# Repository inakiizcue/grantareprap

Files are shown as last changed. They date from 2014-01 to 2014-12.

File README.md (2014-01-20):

grantareprap
============

Configuration, 3D models and tutorials for the prusa mendel i3 we built at the office

Folder structure:

*firmware

Tweaked version of the customized firmware by Marlin. We had to change some values in configuration.h to invert behaviour in some axis.

*Other software

Links and zip files to the rest of the software stack (printrun, slic3r, cad packages)

*3D models

.stl files for printing

How to configure a host for the printer
=======================================

Install all programs in \OtherSoftware

Open \firmware\firmware\it3 minitronics\Marlin-Marlin_v1\Marlin\Marlin.ino in arduino IDE

Connect your computer to the minitronics board in the printer with a USB cable.

Check that LED lights in the minitronics board in the printer light.

Check that all axis of the printer are free to move, the tray is clean of printed parts.

Plug the printer to a power outlet and switch on.

Check that LED lights in printer power supply are on.

Click 'File' -> 'Upload' in Arduino IDE to transfer firmware to printer.

Now the printer is ready to work.

Open \OtherSoftware\Printrun-Win-Slic3r-12July2013\pronterface.exe

Check all printing parameters correspond to the type of plastic (ABS, PLA) used.

Load the .stl or .gcode file for the model to print.

Hit 'print' button.

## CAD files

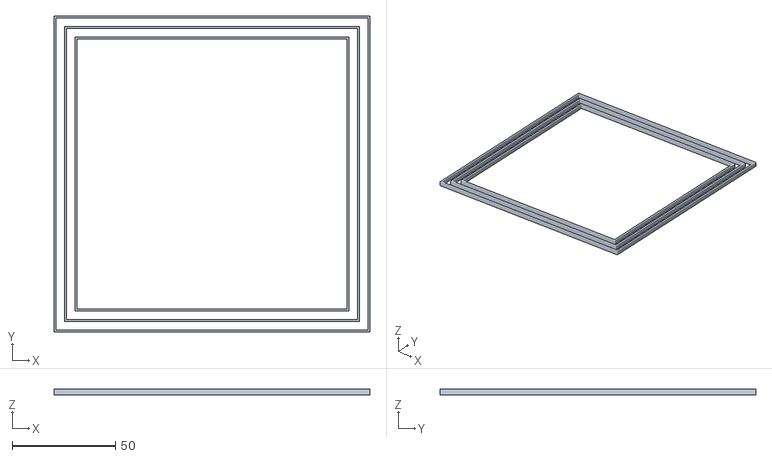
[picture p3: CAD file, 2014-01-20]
3DModels/Bed_Leveling_Calibration_test_object/bedleveling-1.stl
153.0 x 153.0 x 3.00

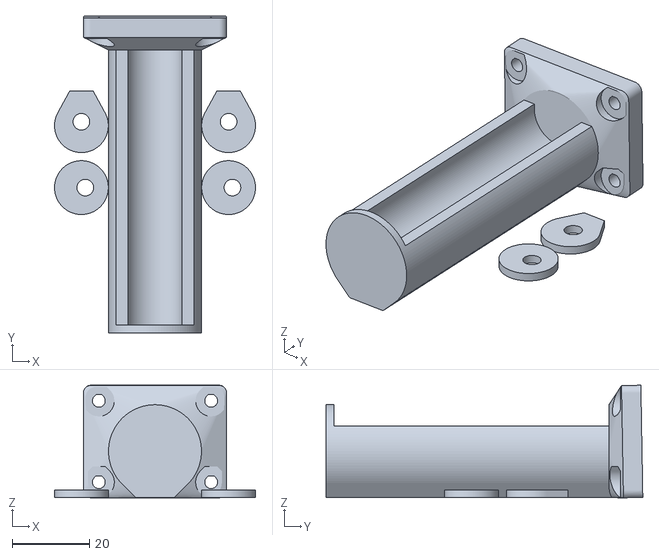
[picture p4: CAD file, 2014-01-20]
3DModels/Parametric_Mendel90_Filament_Spool_Holder/filament_holder_50.stl
51.9 x 81.8 x 29.1

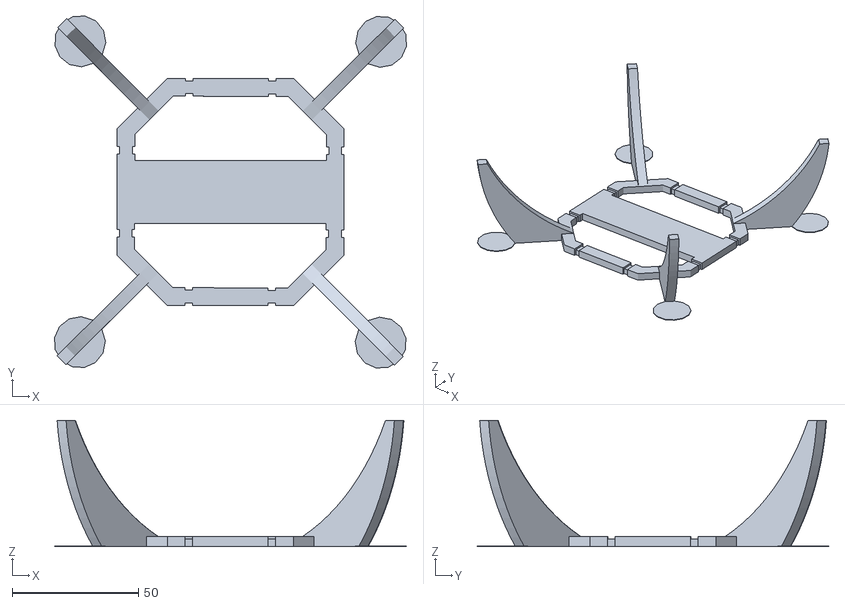
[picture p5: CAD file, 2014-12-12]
3DModels/PL2Q_Hugin/PL2Q_Hugin_legs.stl
139.4 x 139.4 x 50.1

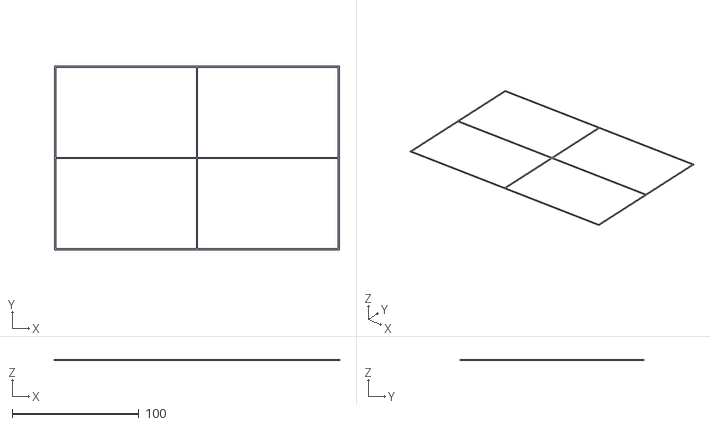
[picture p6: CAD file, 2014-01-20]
3DModels/Print_Bed_Level_Check/LevelRep-30.stl
225.0 x 145.0 x 0.3

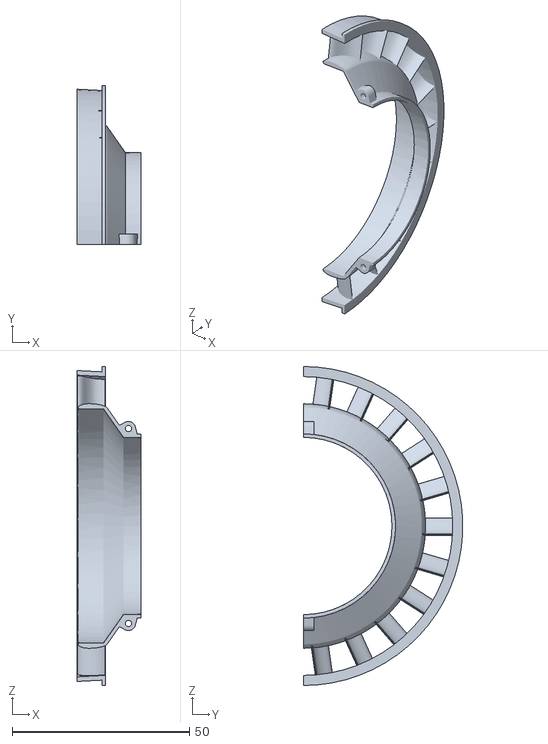
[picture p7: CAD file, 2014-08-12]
3DModels/Turbofan/Low_Bypass_Turbofan_Jet_Engine/compressor case/CC Diffuser.STL
18.0 x 44.9 x 90.0

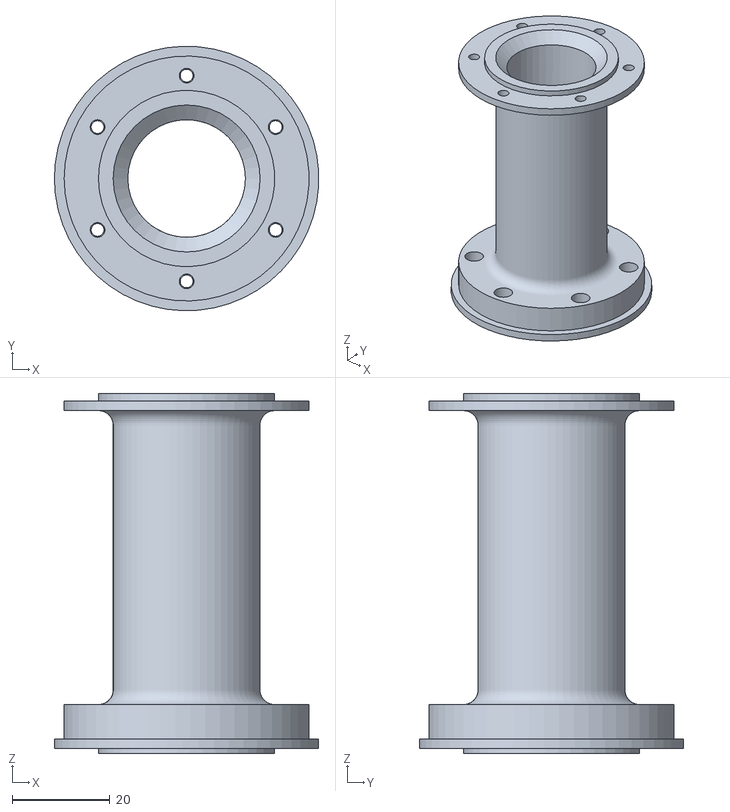
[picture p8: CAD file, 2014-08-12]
3DModels/Turbofan/Low_Bypass_Turbofan_Jet_Engine/HP rotor/spacer CC.STL
54.0 x 54.0 x 73.5

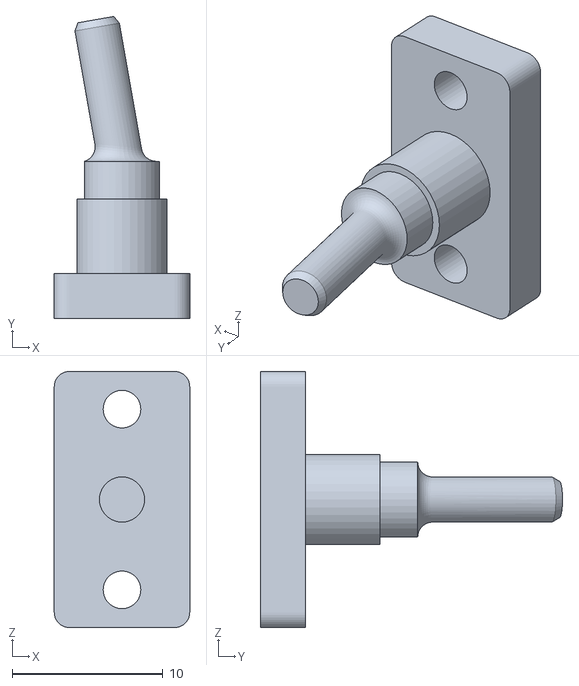
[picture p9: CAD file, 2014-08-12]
3DModels/Turbofan/Low_Bypass_Turbofan_Jet_Engine/Rev_1/fuel nozzle.STL
9.00 x 20.1 x 17.0

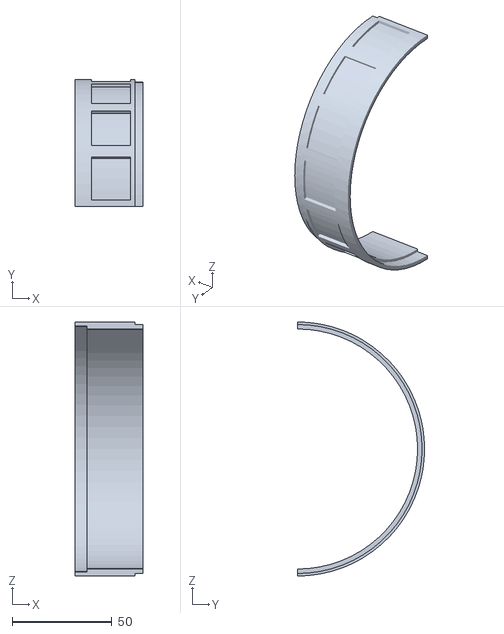
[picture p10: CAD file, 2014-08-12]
3DModels/Turbofan/Low_Bypass_Turbofan_Jet_Engine/turbine_section/turbine section/extetnal can.STL
34.0 x 63.4 x 127.0

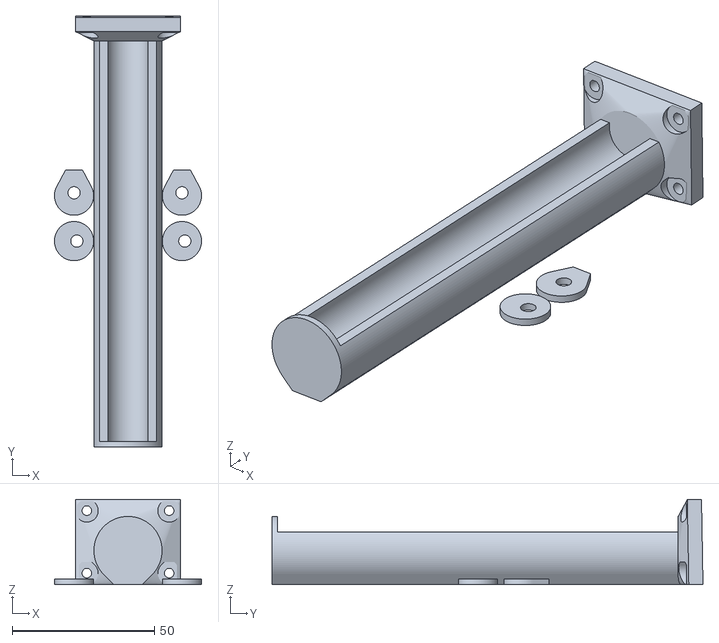
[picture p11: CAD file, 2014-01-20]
3DModels/Parametric_Mendel90_Filament_Spool_Holder/filament_holder_120.stl
51.8 x 151.8 x 30.1

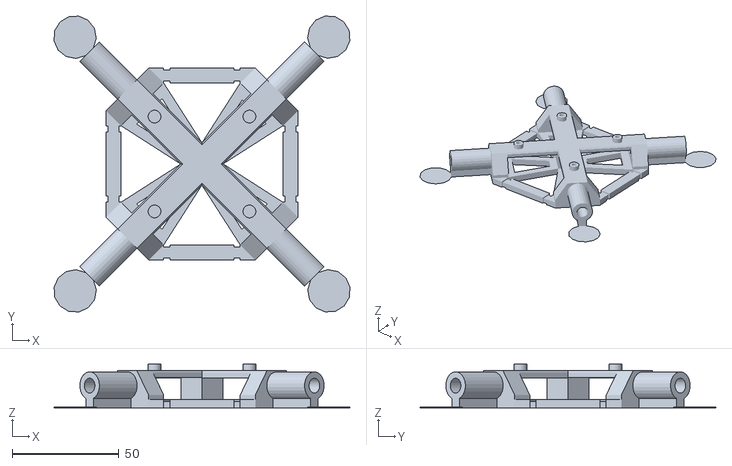
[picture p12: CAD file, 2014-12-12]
3DModels/PL2Q_Hugin/PL2Q_Hugin_body.stl
138.8 x 138.8 x 20.5

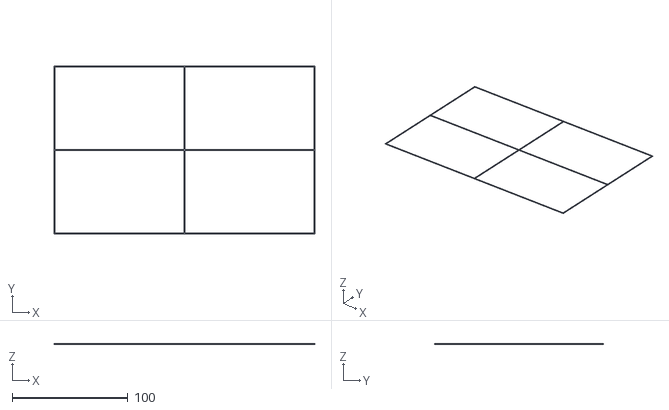
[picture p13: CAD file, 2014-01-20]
3DModels/Print_Bed_Level_Check/LevelRep-10.stl
225.0 x 145.0 x 0.1

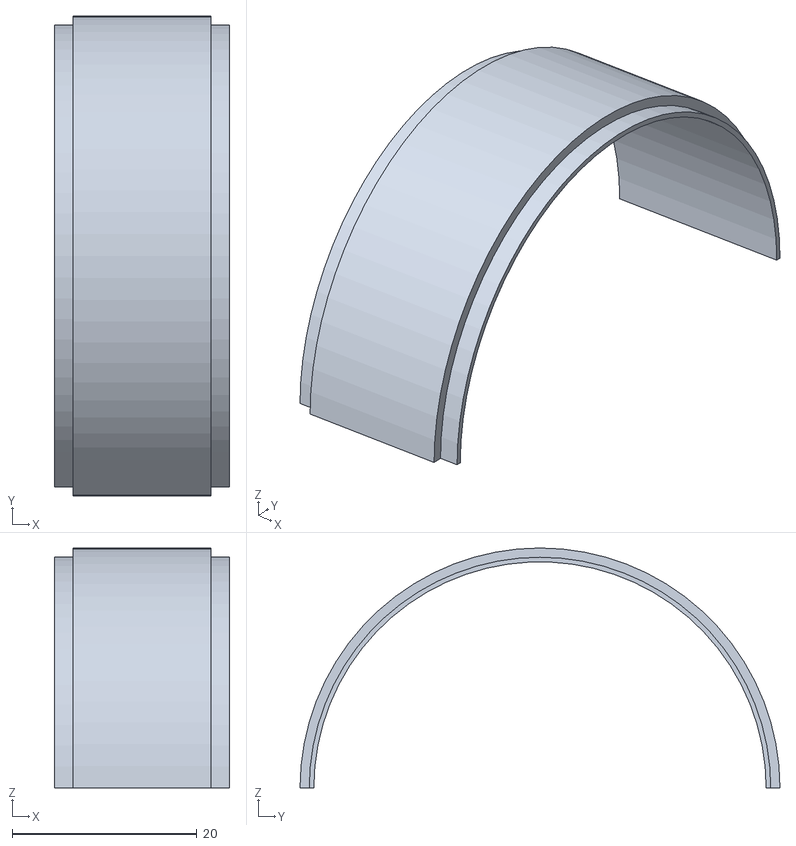
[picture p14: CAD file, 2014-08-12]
3DModels/Turbofan/Low_Bypass_Turbofan_Jet_Engine/compressor case/CC Diffuser 3.STL
19.0 x 52.0 x 26.0

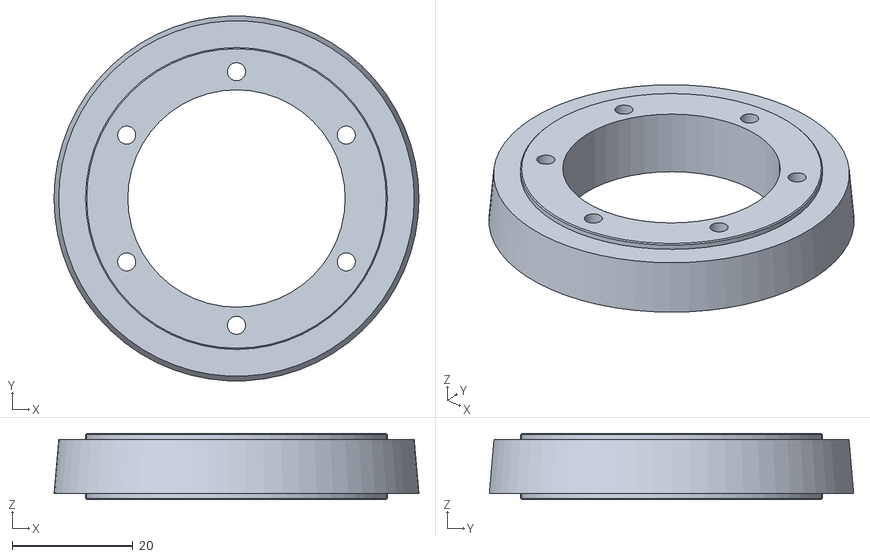
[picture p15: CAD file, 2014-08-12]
3DModels/Turbofan/Low_Bypass_Turbofan_Jet_Engine/HP rotor/R2Spacer.STL
60.5 x 60.4 x 11.0

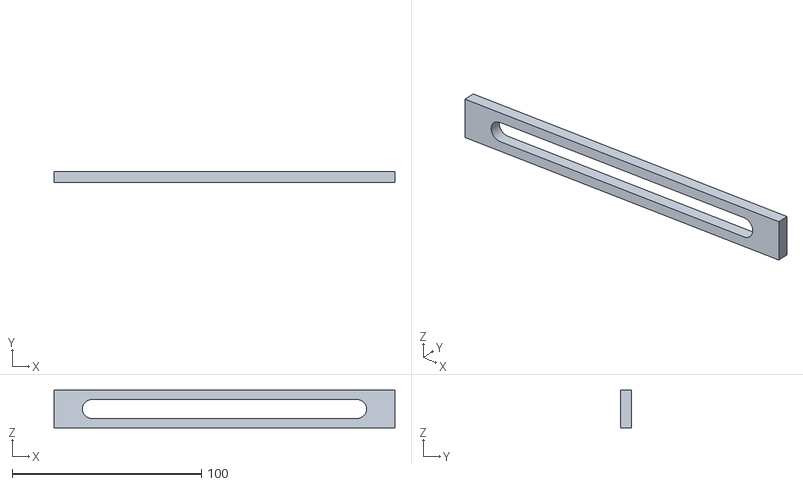
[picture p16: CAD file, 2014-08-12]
3DModels/Turbofan/Low_Bypass_Turbofan_Jet_Engine/Rev_1/distanziale.STL
180.0 x 6.00 x 20.0

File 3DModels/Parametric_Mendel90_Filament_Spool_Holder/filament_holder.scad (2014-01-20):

//
//Yet Another Filament Spool Holder
//
//Designed for the Lasercut Mende90 but can be fitted on most printers with
//a flat surface to bolt it onto.
//
//tony@think3dprint3d.com
//
// GPL v3.0
//
// it uses two libraries from the mendel90 design, available from here:
//
// https://github.com/T3P3/Mendel90/tree/LaserCut/scad
// teardrops.scad
// utils.scad
//
//for the thingiverse customiser the fucntions have been included in this file.

// preview[view:south west, tilt:top diagonal]

//variable defines, all in mm

//##customiser variables##//
// The maximum width of the spool or spools
max_spool_width=50; //[30:150]

//bearing outer diameter 13=624ZZ,21=608ZZ
bearing_od=13; //[13,22]
//bearing inner diameter 4=624ZZ,8=608ZZ
bearing_id=4; //[4,8]
//bearing thickness 5=624ZZ 7=608ZZ
bearing_thickness=5; //[5,7]
//use 25 for 624ZZ and 31 for 608ZZ
min_spool_id=25; //[25,32]

/* [Hidden] */


spool_id_clearance=1; //minimum clearance between the spool holder and the inside of a spool

//##bearing variables##
bearing_washer_thickness=0.5; //M4 washer
bearing_washer_radius=9/2; //M4 washer
bearing_clearance=1; //clearance between the bearings and the spool holder
//a set of two bearings with a washer at each end as a spacer
bearing_stack_thickness=(2*bearing_thickness)+(2*bearing_washer_thickness);
bearing_stack_wall_thickness=2;
//the bolt to hold the stack and plastic walls together
bearing_stack_bolt_length=bearing_stack_thickness+bearing_stack_wall_thickness*2+10;
echo("bearing_stack_bolt_length: ", bearing_stack_bolt_length);

//##filament holder variables##
min_filament_holder_id = bearing_od+bearing_clearance;
max_filament_holder_od = min_spool_id-spool_id_clearance;
filament_holder_wall_thickness= max_filament_holder_od-min_filament_holder_id;
echo("filament_holder_wall_thickness: ", filament_holder_wall_thickness);
filament_holder_length=max_spool_width+bearing_stack_bolt_length;
echo("filament_holder_length: ", filament_holder_length);

//##mounting plate##
fastener_clearance_radius=3.3/2;
fastener_washer_clearance_radius=8/2;
mounting_plate_thickness=8;
mounting_plate_width=min_spool_id+fastener_washer_clearance_radius;
mounting_plate_height=min_spool_id+fastener_washer_clearance_radius*3;


//##miscellaneous##
fn_resolution=100; //quality vs render time
print_clearance=0.1; //additional clearance between two printed objects

//The "peg" like tube the filament reel will sit on
module main_tube(){
rotate([90,0,0])
    difference(){
      rotate([0,0,180])//truncated part facing down
        //use a teardrop to make it printable without support.
        teardrop(filament_holder_length, max_filament_holder_od/2,true,true);

      //cut out for bearings  
      translate([0,(max_filament_holder_od-min_spool_id*4/7),0])
        cube([min_spool_id+5,
              min_filament_holder_id/2,
              filament_holder_length-bearing_stack_wall_thickness*2],center=true);
      translate([0,(max_filament_holder_od-min_filament_holder_id)/2,0])
        cylinder(h=filament_holder_length-bearing_stack_wall_thickness*2,
                 r=min_filament_holder_id/2, $fn=fn_resolution,center=true);
      translate([0,(max_filament_holder_od-min_filament_holder_id/2)/2,0])
        cube([min_filament_holder_id, min_filament_holder_id/2,filament_holder_length-bearing_stack_wall_thickness*2],center=true);

  }
}

//The plate that holds the main tube to the side of the printer
module mounting_plate(){
     $fn=fn_resolution;//smooth rounded rectangle
		difference(){
				hull(){
					translate([0,(mounting_plate_width-max_filament_holder_od)/2,-(filament_holder_length+mounting_plate_thickness)/2 ])
						rotate([1,0,0])//1 degree to compensate for the distortion due to heavy reels
						rounded_rectangle([mounting_plate_height,mounting_plate_width,mounting_plate_thickness-3],2,true);
					translate([0,0,-(filament_holder_length)/2 +bearing_stack_wall_thickness/2+0.5])
						cylinder(h=1, r=max_filament_holder_od/2, $fn=fn_resolution,center=true);
					}				

				//bolt holes
				for(i=[-1,1])
					for(j=[-1,1])
						translate([j*mounting_plate_height/2 - j*fastener_washer_clearance_radius,
										i*mounting_plate_width/2 -i*fastener_washer_clearance_radius 
														+ (mounting_plate_width-max_filament_holder_od)/2,
										-(filament_holder_length+mounting_plate_thickness)/2])
						{
							teardrop(100, fastener_clearance_radius,true,true);
							translate([0,0,(mounting_plate_thickness-2)/2+20])
								teardrop(40, fastener_washer_clearance_radius,true,true);
						}
		}
}


//each bearing stack has two printed ends
module bearing_end(edge=true){
	difference(){
		if(edge) //the bearing end sticks up to prevent the filament roll from coming off
			hull(){
			cylinder(h=bearing_stack_wall_thickness, r=min_filament_holder_id/2-print_clearance/2, $fn=fn_resolution,center=true);
			translate([6,0,0])
				cube([6,6,bearing_stack_wall_thickness],center=true);
			}
		else
			cylinder(h=bearing_stack_wall_thickness, r=min_filament_holder_id/2-print_clearance/2, $fn=fn_resolution,center=true);
			translate([bearing_clearance,0,0])
				cylinder(h=bearing_stack_bolt_length+10,r=bearing_id/2+0.15,$fn=fn_resolution,center=true);
	}
}


module spool_holder_stl(){

	translate([0,0,max_filament_holder_od/2]){
		main_tube();
		rotate([90,0,0])
			translate([0,0,-0.01]) //prevent intersecting faces
			mounting_plate();
	}

	for(i=[-1,1])
		translate([i*(max_filament_holder_od+min_filament_holder_id)/2,0,bearing_stack_wall_thickness/2]){
			bearing_end(false);
			translate([0,min_filament_holder_id+2,0])
				rotate([0,0,90])
					bearing_end(true);
		}
}


module bearing_stack_assembly();
//the printed bearing ends, washers and two bearings
module bearing_stack_assembly(){
  bearing_end(false);
    translate([0,0,bearing_stack_wall_thickness+
              bearing_washer_thickness*2+bearing_thickness*2])
  bearing_end(true);
  //Bearings and washers
  %translate([bearing_clearance,0,bearing_stack_wall_thickness/2+
             bearing_washer_thickness+bearing_thickness])
    difference(){
        union(){
          for(i=[-1,1])
            translate([0,0,i*bearing_thickness+i*bearing_washer_thickness/2])
              cylinder(h=bearing_washer_thickness,
                       r=bearing_washer_radius,
                       $fn=fn_resolution,center=true);
              cylinder(h=bearing_thickness*2,
                       r=bearing_od/2,
                       $fn=fn_resolution,center=true);
         }
         cylinder(h=bearing_stack_thickness+5,
                  r=bearing_id/2,
                  $fn=fn_resolution,center=true);
  }
}

module spool_holder_assembly(){
	main_tube();
	rotate([90,0,0]){
		mounting_plate();
		translate([0,(max_filament_holder_od-min_filament_holder_id)/2,-(max_spool_width/2- (bearing_stack_wall_thickness+
              bearing_washer_thickness*2+bearing_thickness*2))])
			rotate([0,180,-90])
				bearing_stack_assembly();
		translate([0,(max_filament_holder_od-min_filament_holder_id)/2,(max_spool_width/2- (bearing_stack_wall_thickness+
              bearing_washer_thickness*2+bearing_thickness*2))])
			rotate([0,0,90])
				bearing_stack_assembly();
		}
}
// From:
// https://github.com/T3P3/Mendel90/tree/LaserCut/scad
// teardrops.scad
module teardrop_2D(r, truncate = true) {
    difference() {
        union() {
            circle(r = r, center = true,$fn=100);
            translate([0,r / sqrt(2),0])
                rotate([0,0,45])
                    square([r, r], center = true);
        }
        if(truncate)
            translate([0, r * 2, 0])
                square([2 * r, 2 * r], center = true);
    }
}
// From:
// https://github.com/T3P3/Mendel90/tree/LaserCut/scad
// teardrops.scad
module teardrop(h, r, center, truncate = true)
    linear_extrude(height = h, convexity = 2, center = center)
        teardrop_2D(r, truncate);

// From:
// https://github.com/T3P3/Mendel90/tree/LaserCut/scad
// utils.scad
module rounded_square(w, h, r)
{
    union() {
        square([w - 2 * r, h], center = true);
        square([w, h - 2 * r], center = true);
        for(x = [-w/2 + r, w/2 - r])
            for(y = [-h/2 + r, h/2 - r])
                translate([x, y])
                    circle(r = r);
    }
}

// From:
// https://github.com/T3P3/Mendel90/tree/LaserCut/scad
// utils.scad
module rounded_rectangle(size, r, center = true)
{
    w = size[0];
    h = size[1];
    linear_extrude(height = size[2], center = center)
        rounded_square(size[0], size[1], r);
}
//if(1)
//	spool_holder_assembly();
//else
	spool_holder_stl();

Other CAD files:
3DModels/Turbofan/Low_Bypass_Turbofan_Jet_Engine/turbine_section/turbine section/LP turbine case.STL
3DModels/PL2Q_Hugin/request_PL2Q_Hugin_motormount_no_mouse.stl
3DModels/Print_Bed_Level_Check/LevelRep-20.stl
3DModels/Turbofan/Low_Bypass_Turbofan_Jet_Engine/compressor case/s2.STL
3DModels/Print_Bed_Level_Check/BedLevel.scad
3DModels/Bed_Leveling_Calibration_test_object/bedleveling-1.scad
3DModels/PL2Q_Hugin/PL2Q_Hugin.skp
3DModels/PL2Q_Hugin/PL2Q_Hugin_arm.stl
3DModels/PL2Q_Hugin/PL2Q_Hugin_cam_holder.stl
3DModels/PL2Q_Hugin/PL2Q_Hugin_canopy.stl
3DModels/PL2Q_Hugin/PL2Q_Hugin_gopro_legs.stl
3DModels/PL2Q_Hugin/PL2Q_Hugin_gopro_mount.stl
3DModels/PL2Q_Hugin/PL2Q_Hugin_motormount.stl
3DModels/PL2Q_Hugin/PL2Q_Hugin_receiver_canopy.stl
3DModels/PL2Q_Hugin/request_PL2Q_Hugin_arm_no_base_raft.stl
3DModels/PL2Q_Hugin/request_PL2Q_Hugin_body_no_mouse.stl
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

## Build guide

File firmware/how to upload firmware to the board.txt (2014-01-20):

Follow instructions in the website below to install firmware to the minitronics board,
http://reprap.org/wiki/Minitronics_10

 but don't use the latest version of marlin software,

use the one in this folder instead.

If the last version used from the website, minitronics board is not recognized.

the board is in com4

loaded the .ino file in:
C:\Granta\reprap\minitronicstest

and connected board fan, x & y stepper mottors.

uploaded the test to the board, and both motors are moving. The fan works.

copied marlin.pde from wrong marlin firmware above to customized working one. The file didn't exist in the right folder

This didn't make any difference.

Had to tweak configuration.h to invert the limits of all axis/endstops.

Had to invert the soldering for endstop cabling, the switches were always on, preventing moving of motors

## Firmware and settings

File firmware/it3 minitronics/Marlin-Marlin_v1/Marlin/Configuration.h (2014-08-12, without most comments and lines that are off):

#define CONFIGURATION_H
#define STRING_VERSION_CONFIG_H __DATE__ " " __TIME__ // build date and time
#define STRING_CONFIG_H_AUTHOR "(Dani, it3minitronics)" //Who made the changes.
#define SERIAL_PORT 0
#define BAUDRATE 115200
#define MOTHERBOARD 702
#define EXTRUDERS 1
#define POWER_SUPPLY 1
#define TEMP_SENSOR_0 1
#define TEMP_SENSOR_1 0
#define TEMP_SENSOR_2 0
#define TEMP_SENSOR_BED 1
#define TEMP_RESIDENCY_TIME 10 // (seconds)
#define TEMP_HYSTERESIS 3 // (degC) range of +/- temperatures considered "close" to the target one
#define TEMP_WINDOW 1 // (degC) Window around target to start the recidency timer x degC early.
#define HEATER_0_MINTEMP 5
#define HEATER_1_MINTEMP 5
#define HEATER_2_MINTEMP 5
#define BED_MINTEMP 5
#define HEATER_0_MAXTEMP 275
#define HEATER_1_MAXTEMP 275
#define HEATER_2_MAXTEMP 275
#define BED_MAXTEMP 150
#define PIDTEMP
#define BANG_MAX 256 // limits current to nozzle while in bang-bang mode; 256=full current
#define PID_MAX 256 // limits current to nozzle while PID is active (see PID_FUNCTIONAL_RANGE below); 256=full current
  #define PID_FUNCTIONAL_RANGE 10 // If the temperature difference between the target temperature and the actual temperature
  #define PID_INTEGRAL_DRIVE_MAX 255 //limit for the integral term
  #define K1 0.95 //smoothing factor withing the PID
  #define PID_dT ((16.0 * 8.0)/(F_CPU / 64.0 / 256.0)) //sampling period of the temperature routine
    #define DEFAULT_Kp 22.2
    #define DEFAULT_Ki 1.08
    #define DEFAULT_Kd 114
#define MAX_BED_POWER 256 // limits duty cycle to bed; 256=full current
#define PREVENT_DANGEROUS_EXTRUDE
#define PREVENT_LENGTHY_EXTRUDE
#define EXTRUDE_MINTEMP 0
#define EXTRUDE_MAXLENGTH (X_MAX_LENGTH+Y_MAX_LENGTH) //prevent extrusion of very large distances.
#define ENDSTOPPULLUPS // Comment this out (using // at the start of the line) to disable the endstop pullup resistors
  #define ENDSTOPPULLUP_XMAX
  #define ENDSTOPPULLUP_YMAX
  #define ENDSTOPPULLUP_ZMAX
  #define ENDSTOPPULLUP_XMIN
  #define ENDSTOPPULLUP_YMIN
  #define ENDSTOPPULLUP_ZMIN
const bool X_ENDSTOPS_INVERTING = true; // set to true to invert the logic of the endstops.
const bool Y_ENDSTOPS_INVERTING = true; // set to true to invert the logic of the endstops.
const bool Z_ENDSTOPS_INVERTING = true; // set to true to invert the logic of the endstops.
#define X_ENABLE_ON 0
#define Y_ENABLE_ON 0
#define Z_ENABLE_ON 0
#define E_ENABLE_ON 0 // For all extruders
#define DISABLE_X false
#define DISABLE_Y false
#define DISABLE_Z false
#define DISABLE_E false // For all extruders
#define INVERT_X_DIR true // for Mendel set to false, for Orca set to true
#define INVERT_Y_DIR false// for Mendel set to true, for Orca set to false
#define INVERT_Z_DIR false // for Mendel set to false, for Orca set to true
#define INVERT_E0_DIR true // for direct drive extruder v9 set to true, for geared extruder set to false
#define INVERT_E1_DIR false // for direct drive extruder v9 set to true, for geared extruder set to false
#define INVERT_E2_DIR false // for direct drive extruder v9 set to true, for geared extruder set to false
#define X_HOME_DIR -1
#define Y_HOME_DIR -1
#define Z_HOME_DIR -1
#define min_software_endstops false //If true, axis won't move to coordinates less than HOME_POS.
#define max_software_endstops true //If true, axis won't move to coordinates greater than the defined lengths below.
#define X_MAX_POS 205
#define X_MIN_POS 0
#define Y_MAX_POS 205
#define Y_MIN_POS 0
#define Z_MAX_POS 200
#define Z_MIN_POS 0
#define X_MAX_LENGTH (X_MAX_POS - X_MIN_POS)
#define Y_MAX_LENGTH (Y_MAX_POS - Y_MIN_POS)
#define Z_MAX_LENGTH (Z_MAX_POS - Z_MIN_POS)
#define MANUAL_X_HOME_POS 0
#define MANUAL_Y_HOME_POS 0
#define MANUAL_Z_HOME_POS 0
#define NUM_AXIS 4 // The axis order in all axis related arrays is X, Y, Z, E
#define HOMING_FEEDRATE {50*60, 50*60, 4*30, 0} // set the homing speeds (mm/min)
#define DEFAULT_AXIS_STEPS_PER_UNIT {160,160,7920,1530} // default bcndynamics setting for prusa i3
#define DEFAULT_MAX_FEEDRATE {500, 500, 5, 25} // (mm/sec) bcndynamics default setting
#define DEFAULT_MAX_ACCELERATION {9000,9000,100,10000} // X, Y, Z, E maximum start speed for accelerated moves. E default values are good for skeinforge 40+, for older versions raise them a lot.
#define DEFAULT_ACCELERATION 3000 // X, Y, Z and E max acceleration in mm/s^2 for printing moves
#define DEFAULT_RETRACT_ACCELERATION 3000 // X, Y, Z and E max acceleration in mm/s^2 for r retracts
#define DEFAULT_XYJERK 20.0 // (mm/sec)
#define DEFAULT_ZJERK 0.4 // (mm/sec)
#define DEFAULT_EJERK 5.0 // (mm/sec)
#define PLA_PREHEAT_HOTEND_TEMP 180
#define PLA_PREHEAT_HPB_TEMP 70
#define PLA_PREHEAT_FAN_SPEED 255 // Insert Value between 0 and 255
#define ABS_PREHEAT_HOTEND_TEMP 240
#define ABS_PREHEAT_HPB_TEMP 100
#define ABS_PREHEAT_FAN_SPEED 255 // Insert Value between 0 and 255
#include "Configuration_adv.h"
#include "thermistortables.h"

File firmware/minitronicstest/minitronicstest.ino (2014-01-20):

#include "thermistortables.h"



 
 #define X_STEP_PIN 48
 #define X_DIR_PIN 47
 #define X_ENABLE_PIN 49
 #define X_MIN_PIN 5
 #define X_MAX_PIN -1 //2 //Max endstops default to disabled "-1", set to commented value to enable.
 
 #define Y_STEP_PIN 39 // A6
 #define Y_DIR_PIN 40 // A0
 #define Y_ENABLE_PIN 38
 #define Y_MIN_PIN 2
 #define Y_MAX_PIN -1 //15
 
 #define Z_STEP_PIN 42 // A2
 #define Z_DIR_PIN 43 // A6
 #define Z_ENABLE_PIN 41 // A1
 #define Z_MIN_PIN 6
 #define Z_MAX_PIN -1
 
#define E_STEP_PIN         45
#define E_DIR_PIN          44
#define E_ENABLE_PIN       27



#define SDPOWER            -1

#define EXTRUDERS 3

#define TEMP_SENSOR_AD595_OFFSET 0.0
#define TEMP_SENSOR_AD595_GAIN   1.0

#define THERMISTORHEATER_0 1
#define THERMISTORHEATER_1 1
#define THERMISTORHEATER_2 1

#define HEATER_0_USES_THERMISTOR 1
#define HEATER_1_USES_THERMISTOR 1
#define HEATER_2_USES_THERMISTOR 1

  static void *heater_ttbl_map[EXTRUDERS] = { (void *)heater_0_temptable
#if EXTRUDERS > 1
                                            , (void *)heater_1_temptable
#endif
#if EXTRUDERS > 2
                                            , (void *)heater_2_temptable
#endif
#if EXTRUDERS > 3
  #error Unsupported number of extruders
#endif
  };
  
    static int heater_ttbllen_map[EXTRUDERS] = { heater_0_temptable_len
#if EXTRUDERS > 1
                                             , heater_1_temptable_len
#endif
#if EXTRUDERS > 2
                                             , heater_2_temptable_len
#endif
#if EXTRUDERS > 3
  #error Unsupported number of extruders
#endif
  };
  
  #define PGM_RD_W(x)   (short)pgm_read_word(&x)

#define SDSS               53
#define LED_PIN            46




#define KILL_PIN           -1

#define HEATER_0_PIN       9
#define HEATER_1_PIN       8
#define HEATER_2_PIN       7
#define HEATER_3_PIN       3

#define TEMP_0_PIN         7  // ANALOG NUMBERING
#define TEMP_1_PIN         6   // ANALOG NUMBERING




void setup() {

  pinMode(TEMP_0_PIN  , INPUT);
  pinMode(TEMP_1_PIN  , INPUT);
  pinMode(X_MIN_PIN  , INPUT);
  pinMode(Y_MIN_PIN  , INPUT);
  pinMode(Z_MIN_PIN  , INPUT);
  


  pinMode(HEATER_0_PIN , OUTPUT);
  pinMode(HEATER_1_PIN , OUTPUT);
  pinMode(HEATER_2_PIN , OUTPUT);
  pinMode(HEATER_3_PIN , OUTPUT);
  pinMode(LED_PIN  , OUTPUT);
  
  pinMode(X_STEP_PIN  , OUTPUT);
  pinMode(X_DIR_PIN    , OUTPUT);
  pinMode(X_ENABLE_PIN    , OUTPUT);
  
  pinMode(Y_STEP_PIN  , OUTPUT);
  pinMode(Y_DIR_PIN    , OUTPUT);
  pinMode(Y_ENABLE_PIN    , OUTPUT);
  
  pinMode(Z_STEP_PIN  , OUTPUT);
  pinMode(Z_DIR_PIN    , OUTPUT);
  pinMode(Z_ENABLE_PIN    , OUTPUT);
  
  pinMode(E_STEP_PIN  , OUTPUT);
  pinMode(E_DIR_PIN    , OUTPUT);
  pinMode(E_ENABLE_PIN    , OUTPUT);
  

  
   digitalWrite(X_ENABLE_PIN    , LOW);
    digitalWrite(Y_ENABLE_PIN    , LOW);
    digitalWrite(Z_ENABLE_PIN    , LOW);
    digitalWrite(E_ENABLE_PIN    , LOW);

    Serial.begin(115200);
    
      Serial.print("\nInitializing SD card...");
  
;


}



float analog2temp(int raw, uint8_t e2) {

  #ifdef HEATER_0_USES_MAX6675
    if (e2 == 0)
    {
      return 0.25 * raw;
    }
  #endif

  if(heater_ttbl_map[e2] != 0)
  {
    float celsius = 0;
    byte i;  
    short (*tt)[][2] = (short (*)[][2])(heater_ttbl_map[e2]);

    raw = (1023 * OVERSAMPLENR) - raw;
    for (i=1; i<heater_ttbllen_map[e2]; i++)
    {
      if ((PGM_RD_W((*tt)[i][0]) > raw) && ((float)(PGM_RD_W((*tt)[i][0]) - PGM_RD_W((*tt)[i-1][0])) >0))
      {
        celsius = PGM_RD_W((*tt)[i-1][1]) + 
          (raw - PGM_RD_W((*tt)[i-1][0])) * 
          (float)(PGM_RD_W((*tt)[i][1]) - PGM_RD_W((*tt)[i-1][1])) /
          (float)(PGM_RD_W((*tt)[i][0]) - PGM_RD_W((*tt)[i-1][0]));
        break;
      }
    }

    // Overflow: Set to last value in the table
    if (i == heater_ttbllen_map[e2]) celsius = PGM_RD_W((*tt)[i-1][1]);

    return celsius;
  }
  return ((raw * ((5.0 * 100.0) / 1024.0) / OVERSAMPLENR) * TEMP_SENSOR_AD595_GAIN) + TEMP_SENSOR_AD595_OFFSET;
}

unsigned long prevMillis;

void loop () {
  

  
  if (millis() %1000 <500) 
    digitalWrite(LED_PIN, HIGH);
  else
   digitalWrite(LED_PIN, LOW);
  
  if (millis() %1000 <250) {
    digitalWrite(HEATER_0_PIN, LOW);
    digitalWrite(HEATER_1_PIN, LOW);
    digitalWrite(HEATER_2_PIN, LOW);
    digitalWrite(HEATER_3_PIN, HIGH);
  } else if (millis() %1000 <500) {
    digitalWrite(HEATER_0_PIN, HIGH);
    digitalWrite(HEATER_1_PIN, LOW);
    digitalWrite(HEATER_2_PIN, LOW);
    digitalWrite(HEATER_3_PIN, LOW);
   } else if (millis() %1000 <750) {
    digitalWrite(HEATER_0_PIN, LOW);
    digitalWrite(HEATER_1_PIN, HIGH);
    digitalWrite(HEATER_2_PIN, LOW);
    digitalWrite(HEATER_3_PIN, LOW);
  } else  {
    digitalWrite(HEATER_0_PIN, LOW);
    digitalWrite(HEATER_1_PIN, LOW);
    digitalWrite(HEATER_2_PIN, HIGH);
    digitalWrite(HEATER_3_PIN, LOW);
  }
  
  if (millis() %2000 <1000) {
    digitalWrite(X_DIR_PIN    , HIGH);
    digitalWrite(Y_DIR_PIN    , HIGH);
    digitalWrite(Z_DIR_PIN    , HIGH);
    digitalWrite(E_DIR_PIN    , HIGH);

  }
  else {
    digitalWrite(X_DIR_PIN    , LOW);
    digitalWrite(Y_DIR_PIN    , LOW);
    digitalWrite(Z_DIR_PIN    , LOW);
    digitalWrite(E_DIR_PIN    , LOW);

  }
  
  
    digitalWrite(X_STEP_PIN    , HIGH);
    digitalWrite(Y_STEP_PIN    , HIGH);
    digitalWrite(Z_STEP_PIN    , HIGH);
    digitalWrite(E_STEP_PIN    , HIGH);

  delay(1);
  
  
  
    
    digitalWrite(X_STEP_PIN    , LOW);
    digitalWrite(Y_STEP_PIN    , LOW);
    digitalWrite(Z_STEP_PIN    , LOW);
    digitalWrite(E_STEP_PIN    , LOW);

    
    if (millis() -prevMillis >100){
    prevMillis=millis();
    

    

    int t = analogRead( TEMP_0_PIN);
    Serial.print("T1 ");
    Serial.print(t);
    Serial.print("/");
    Serial.print(analog2temp(1024 - t,0),0);
    

    
    Serial.print(" T2 ");
    t = analogRead( TEMP_1_PIN);
    Serial.print(t);
    Serial.print("/");
    Serial.print(analog2temp(1024 - t,1),0);
    
    Serial.print(" E1 ");
    t = digitalRead( X_MIN_PIN);
    Serial.print(t);
    
    Serial.print(" E2 ");
    t = digitalRead( Y_MIN_PIN);
    Serial.print(t);
    
    Serial.print(" E3 ");
    t = digitalRead( Z_MIN_PIN);
    Serial.println(t);
 

    }



}

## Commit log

2014-01-20 initial commit with all files used for building and configuring the printer
    [Configuration.h, Configuration_adv.h, Menu Plans.xlsx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]
2014-01-20 3d models for filament holder and printing test
    [BedLevel.scad, LevelRep-10.stl, LevelRep-20.stl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]
2014-08-12 latest changes to bedleveling test object, firmware
    [Configuration.h]
2014-08-12 some 3D models
    [CC Diffuser 2.STL, CC Diffuser 3.STL, CC Diffuser.STL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]
2014-12-12 quadcopter drone files
    [PL2Q_Hugin.skp, PL2Q_Hugin_arm.stl, PL2Q_Hugin_body.stl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]
